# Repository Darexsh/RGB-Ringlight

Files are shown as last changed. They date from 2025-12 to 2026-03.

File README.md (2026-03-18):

* * *

<div align="center">

🌈 RGB Ringlight – LED Chaser
============================

**🟥🟩🟦 RGB LED Chaser using 3 mm LEDs**  

Powered by NE555, CD4017, and a speed control potentiometer

  

   
<sub>Check out my bot in Telegram for an easy project overview.<br>If you want to support more projects, you can leave a small donation for a coffee.</sub>

</div>

* * *

✨ Authors
---------

| Name | GitHub | Role | Contact | Contributions |
| --- | --- | --- | --- | --- |
| **[Darexsh by Daniel Sichler](https://github.com/Darexsh)** | [Link](https://github.com/Darexsh?tab=repositories) | Hardware & Schematic 🖥️🛠️| 📧 [E-Mail](mailto:sichler.daniel@gmail.com) | Concept, Layout, Integration |

* * *

🚀 About the Project
--------------------

This project is an **RGB ring light with a chaser animation**, built entirely from discrete electronics.
The core consists of:
* **NE555:** Clock Generator
* **CD4017:** Decade Counter
* **24 LEDs:** Positioned in Circle shape with with alternatingly positioned red, green and blue LEDs
    
The **chase speed** can be adjusted using a **10 kΩ potentiometer**.
Power is supplied through a **9 V barrel jack (5.5 mm)**.

* * *

🛠️ How It Works
===========

🔁 **Main Function**
* The **NE555** operates in astable mode, generating a variable clock signal.
* The **CD4017** advances one output pin per clock pulse.
* Each LED lights up sequentially → creating the classic **LED chaser effect**.

💡 **LED Layout**

The ring contains **24 LEDs** total:
* 🔴 **D1–D8:** Red
* 🟢 **D9–D16:** Green
* 🔵 **D17–D24:** Blue

🎚️ **Speed Control**
* A **10 kΩ potentiometer (RV1)** adjusts the NE555 frequency.

🔌 **Power Supply**
* **9 V DC input**
* Supplied through a **5.5 mm barrel jack**

* * *

📋 Bill of Materials (BOM)
===========

| Part | Value / Type |
| --- | --- |
| **IC1** | CD4017BE |
| **IC2** | NE555P |
| **LEDs** | 24× 3 mm LEDs (8× red, 8× green, 8× blue) |
| **R1–R24** | 680 Ω |
| **R25** | 10 kΩ |
| **RV1** | 10 kΩ potentiometer |
| **C1** | 10 µF / 25 V |
| **J1** | DC barrel jack 5.5 mm (with switch) |
| **J2** | Socket for CD4017 |
| **J3** | Socket for NE555 |
| **H1** | Mounting hole |

* * *

📜 License
----------

This project is licensed under the **Non-Commercial Software License (MIT-style) v1.0** and was developed as an educational project. You are free to use, modify, and distribute the code for **non-commercial purposes only**, and must credit the author:

**Copyright (c) 2025 Darexsh by Daniel Sichler**

Please include the following notice with any use or distribution:

> Developed by Daniel Sichler aka Darexsh. Licensed under the Non-Commercial Software License (MIT-style) v1.0. See `LICENSE` for details.

The full license is available in the [LICENSE](LICENSE) file.

* * *

<!-- Keep this line! Rendered picture of PCB is going to be displayed after Production files are pushed to branch! -->
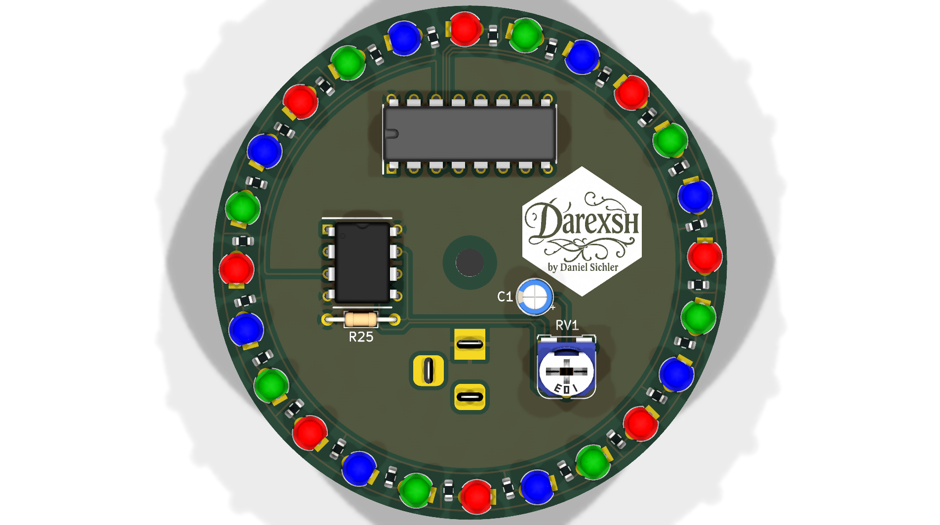
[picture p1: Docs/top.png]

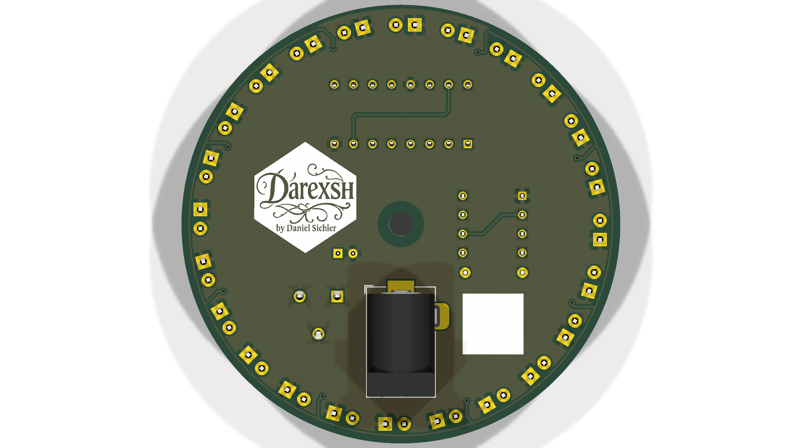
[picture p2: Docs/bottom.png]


<div align="center"> <sub>Created with ❤️ by Daniel Sichler</sub> </div>

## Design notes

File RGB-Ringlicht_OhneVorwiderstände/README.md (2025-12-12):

# KiCAD Project Template
<!-- Keep this line! Rendered picture of PCB will be displayed after production files are pushed to branch -->

This template provides a clean KiCad repository structure for embedded hardware projects, including a GUI-based import script (`kicad_library_manager`) for component management.

---

## Features

Clean structure for hardware development with automated component import and library management.

**DISCLAIMER:** KiCad files are difficult to edit simultaneously. Limit active work on project files to one person at a time; other tasks like research or tests can be done in parallel.

---

## Getting Started

1. **Clone the repository:**

```bash
git clone https://github.com/Ihysol/kicad-template.git
```

2. **Set up your KiCad project:**

* Add symbols, footprints, and 3D models in `Lib-*` folders
* Check for existing footprints online (ComponentSearchEngine, Mouser, Digi-Key)
* Add parts either using the `kicad_library_manager` GUI or manually
* By default, `kicad_library_manager` uses the `library_input` folder located in the `kicad_library_manager` folder to read component files
* Keep all other libraries local; do not use global libraries

3. **Update this README** to describe your project

---

## Ordering Your PCB

* Use Git tags for PCBs sent to production to snapshot the PCB at that moment
* Use the [KiCAD BOM Mouser Order Script](https://github.com/Ihysol/KiCAD_BOM_Mouser_Order_Script) to generate a BOM cart automatically

---

## Folder Structure

* **Hardware/**: KiCad files, symbols, footprints, and 3D models. Add custom footprints here
* **Production/**: Final Gerber files for PCB ordering
* **Docs/**: Documentation, notes, and changelogs. Link datasheets externally and update after production

---

## Version Control

* Use the main branch for the current hardware version
* Tag commits corresponding to production-ready PCBs (e.g., `v1.0`)
* Keep each repository dedicated to a single hardware design
* Use separate repositories for multiple PCB projects

---

## Scripts & Tools

* The `kicad_library_manager` GUI is located in `Hardware/cse_manager/`
* Imports and organizes components automatically
* Can be run as a Python script or standalone executable
* By default, it uses the `library_input` folder inside the `cse_makicad_library_managernager` folder to read component files

---

## Best Practices

* Always include local libraries in the repository; avoid using global KiCad libraries
* Use tags to reference production-ready hardware versions
* Limit simultaneous editing on KiCad files to **one person** at a time

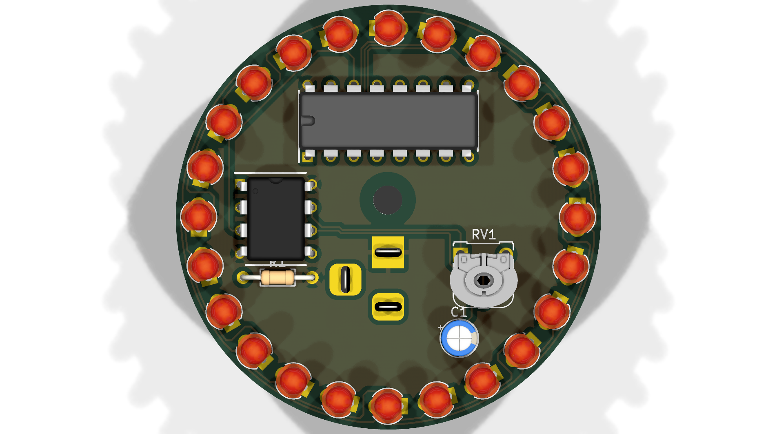
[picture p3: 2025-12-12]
RGB-Ringlicht_OhneVorwiderstände/Hardware/top.png

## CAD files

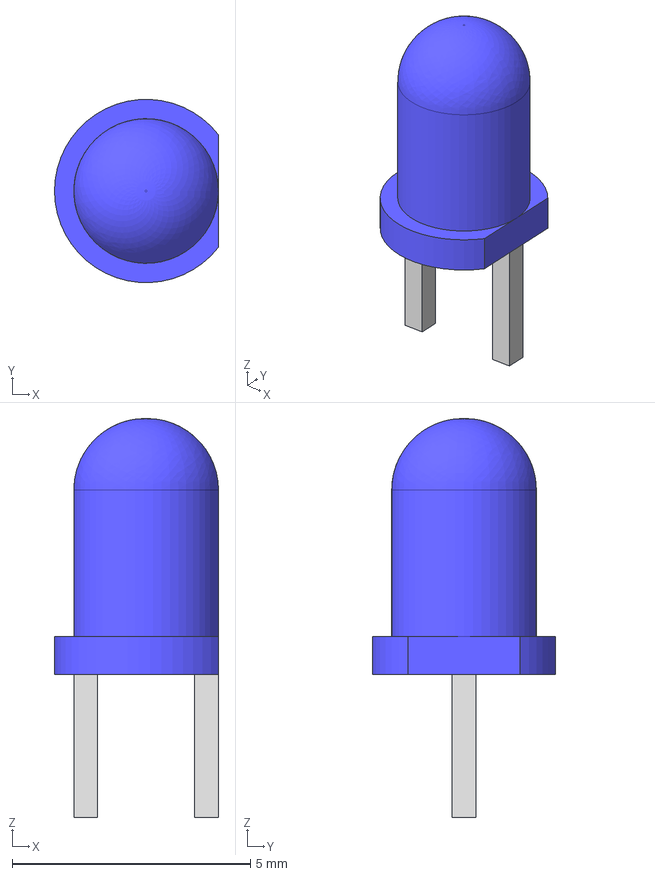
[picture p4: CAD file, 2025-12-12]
Hardware/3dmodels/LED 3mm Blue 3mm Leads.step
3.45 x 3.85 x 8.38 mm
LEDBody
Lead1Body
Lead2Body

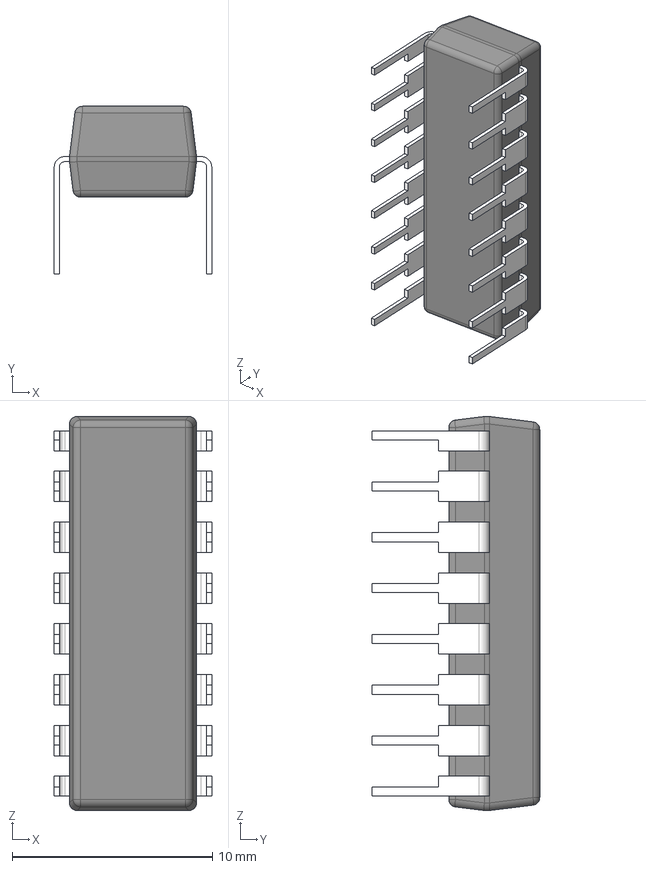
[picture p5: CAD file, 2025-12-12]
RGB-Ringlicht_OhneVorwiderstände/Hardware/3dmodels/CD4017BE.stp
7.87 x 8.37 x 19.7 mm
BODY_N0016A_AF0
LEAD_N0016A_AF1
LEAD_N0016A x 10
LEAD_N0016A_AF3
LEAD_N0016A_AF5
LEAD_N0016A_AF0
LEAD_N0016A_AF2
LEAD_N0016A_AF4

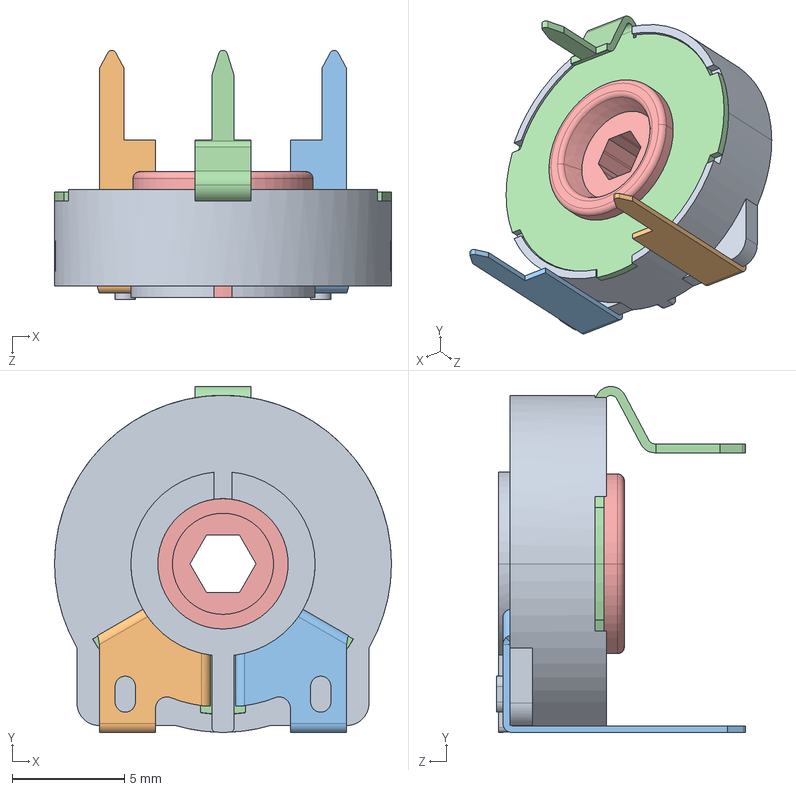
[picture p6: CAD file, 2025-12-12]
RGB-Ringlicht_OhneVorwiderstände/Hardware/3dmodels/Same_Sky_PTN15-F100HB20-H.step
15.0 x 15.4 x 11.1 mm
PTN15 HOUSING
PTN15 VERT TERMINALS
PTN15-F WIPER
PTN15 HEXAGONAL ROTOR

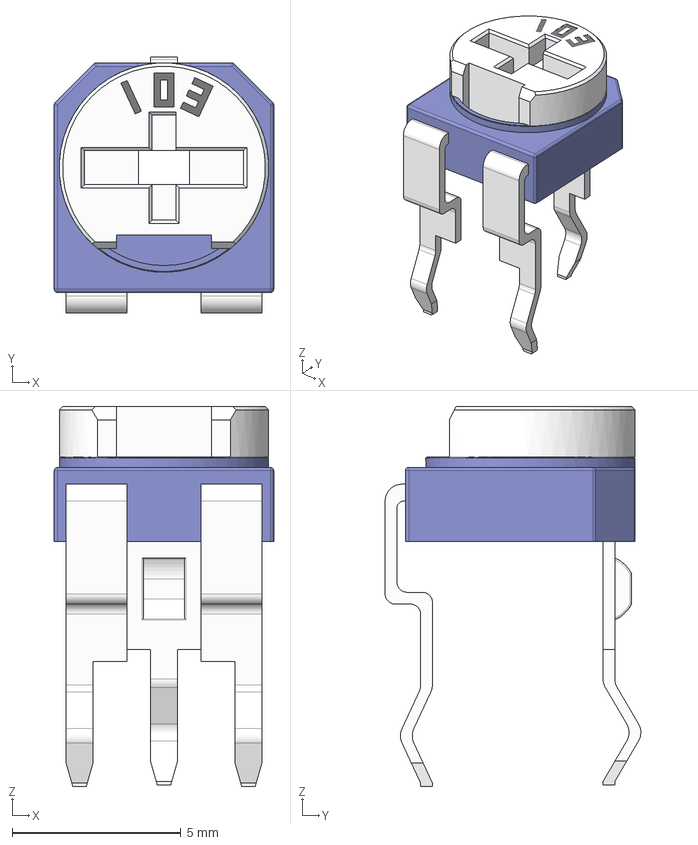
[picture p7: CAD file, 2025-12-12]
Hardware/3dmodels/Trim_Potentiometer_103.step
6.50 x 7.57 x 11.2 mm

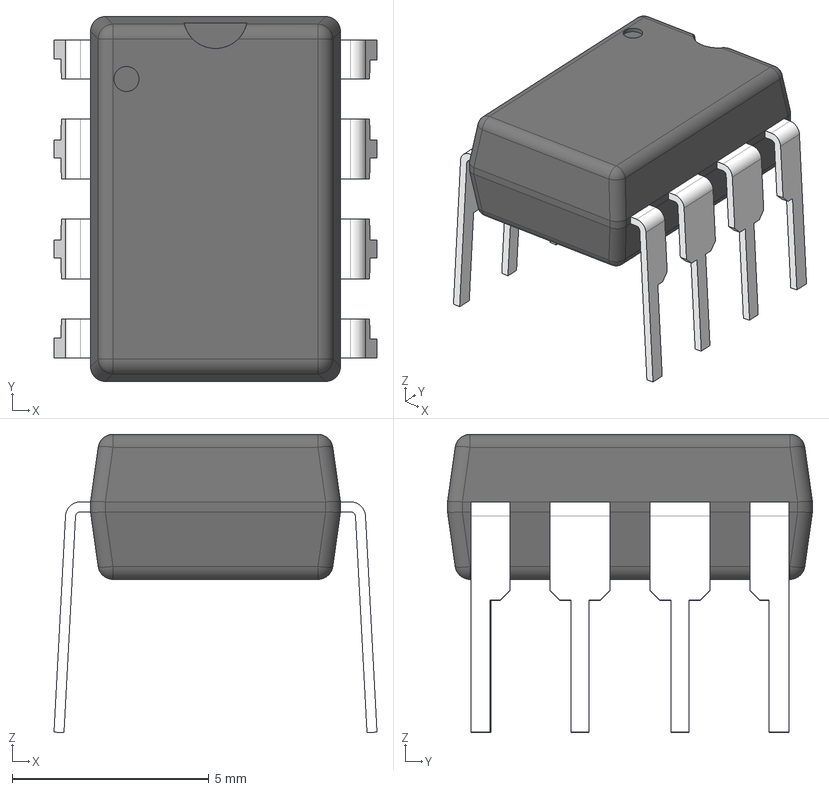
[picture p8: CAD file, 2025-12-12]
RGB-Ringlicht_OhneVorwiderstände/Hardware/3dmodels/NE555P.stp
8.20 x 9.27 x 7.58 mm
BODY_P0008A
LEAD_P0008A x 4
LD_LHALF_P0008A x 2
LD_RHALF_P0008A x 2

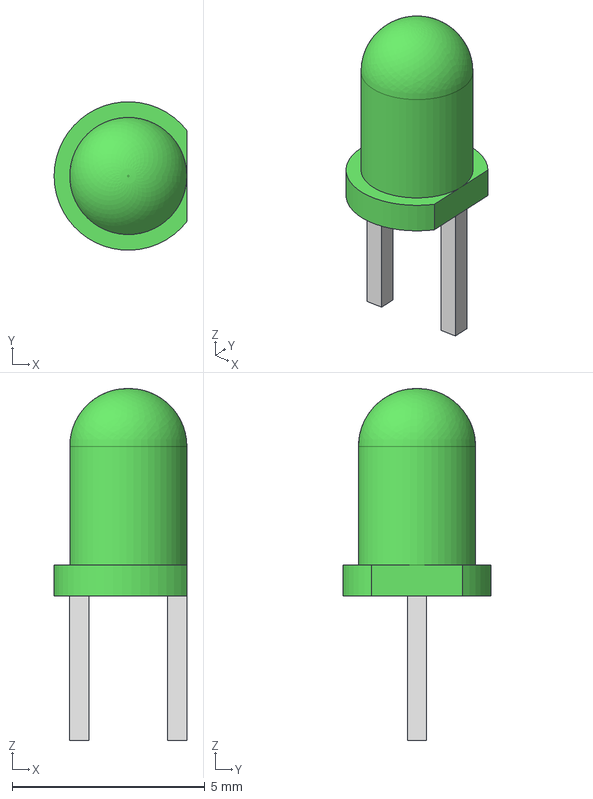
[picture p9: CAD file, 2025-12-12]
Hardware/3dmodels/LED 3mm Green 3mm Leads.step
3.45 x 3.85 x 9.13 mm
LEDBody
Lead1Body
Lead2Body

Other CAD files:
Hardware/3dmodels/LED 3mm Red 3mm Leads.step

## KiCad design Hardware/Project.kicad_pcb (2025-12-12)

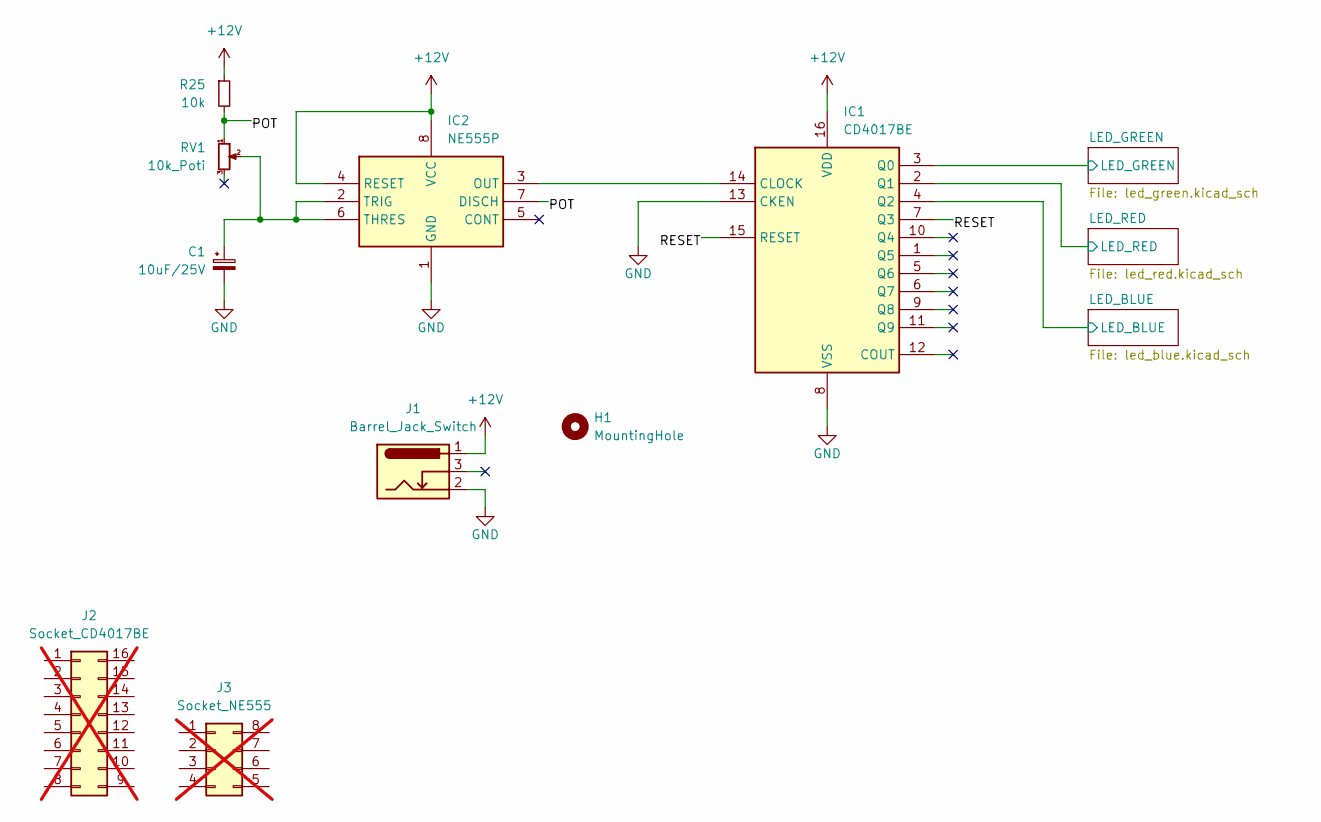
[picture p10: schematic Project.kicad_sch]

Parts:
C1: 10uF/25V; CP_Radial_D4.0mm_P2.00mm; LCSC C43347
H1: MountingHole; MountingHole_3.2mm_M3
IC1: CD4017BE; LCSC C51898328
IC2: NE555P; LCSC C51927330
J1: Barrel_Jack_Switch; BarrelJack_Horizontal; LCSC C3096082
J2: Socket_CD4017BE; LCSC C2326; not fitted
J3: Socket_NE555; LCSC C72124; not fitted
R25: 10k; R_Axial_DIN0204_L3.6mm_D1.6mm_P7.62mm_Horizontal; LCSC C2903232
RV1: 10k_Poti; Potentiometer_Runtron_RM-065_Vertical; LCSC C5205021

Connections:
+12V: IC1.16 (VDD), IC2.4 (RESET), IC2.8 (VCC), J1.1, R25.1
/LED_BLUE/LED_BLUE: IC1.4 (Q2); also elsewhere on the board
/LED_GREEN/LED_GREEN: IC1.3 (Q0); also elsewhere on the board
/LED_RED/LED_RED: IC1.2 (Q1); also elsewhere on the board
/POT: IC2.7 (DISCH), R25.2, RV1.1
/RESET: IC1.7 (Q3), IC1.15 (RESET)
GND: C1.2, IC1.8 (VSS), IC1.13 (CKEN), IC2.1 (GND), J1.2; also elsewhere on the board
unnamed: IC1.14 (CLOCK), IC2.3 (OUT)
unnamed: C1.1, IC2.2 (TRIG), IC2.6 (THRES), RV1.2

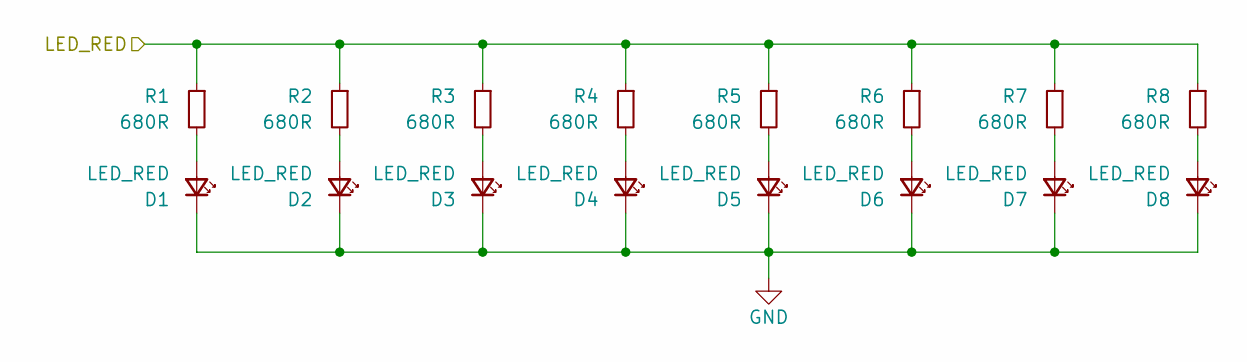
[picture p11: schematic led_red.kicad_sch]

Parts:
D1, D2, D3, D4, D5, D6, D7, D8: LED_RED; LED_D3.0mm; LCSC C2895470
R1, R2, R3, R4, R5, R6, R7, R8: 680R; R_0603_1608Metric

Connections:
/LED_RED/LED_RED: R1.1, R2.1, R3.1, R4.1, R5.1, R6.1, R7.1, R8.1; also elsewhere on the board
GND: D1.1 (K), D2.1 (K), D3.1 (K), D4.1 (K), D5.1 (K), D6.1 (K), D7.1 (K), D8.1 (K); also elsewhere on the board
unnamed: D1.2 (A), R1.2
unnamed: D2.2 (A), R2.2
unnamed: D3.2 (A), R3.2
unnamed: D4.2 (A), R4.2
unnamed: D5.2 (A), R5.2
unnamed: D6.2 (A), R6.2
unnamed: D7.2 (A), R7.2
unnamed: D8.2 (A), R8.2

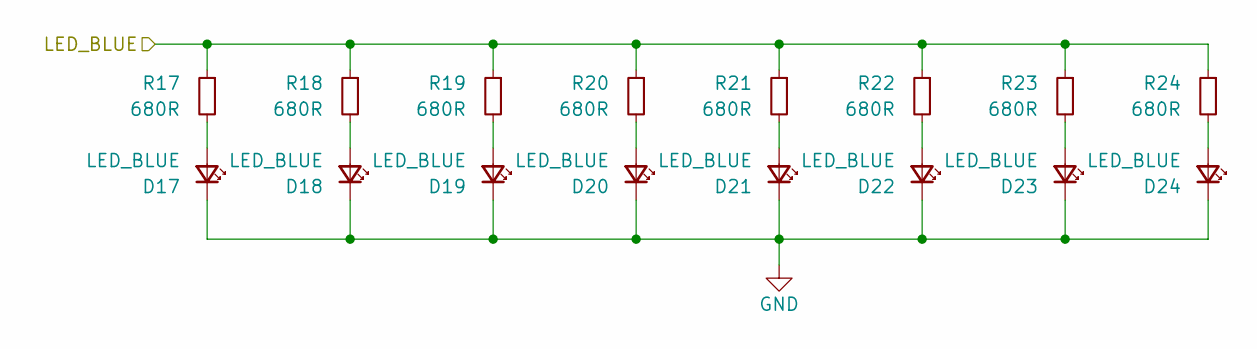
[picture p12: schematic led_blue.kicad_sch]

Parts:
D17, D18, D19, D20, D21, D22, D23, D24: LED_BLUE; LED_D3.0mm; LCSC C2895474
R17, R18, R19, R20, R21, R22, R23, R24: 680R; R_0603_1608Metric

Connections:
/LED_BLUE/LED_BLUE: R17.1, R18.1, R19.1, R20.1, R21.1, R22.1, R23.1, R24.1; also elsewhere on the board
GND: D17.1 (K), D18.1 (K), D19.1 (K), D20.1 (K), D21.1 (K), D22.1 (K), D23.1 (K), D24.1 (K); also elsewhere on the board
unnamed: D17.2 (A), R17.2
unnamed: D18.2 (A), R18.2
unnamed: D19.2 (A), R19.2
unnamed: D20.2 (A), R20.2
unnamed: D21.2 (A), R21.2
unnamed: D22.2 (A), R22.2
unnamed: D23.2 (A), R23.2
unnamed: D24.2 (A), R24.2

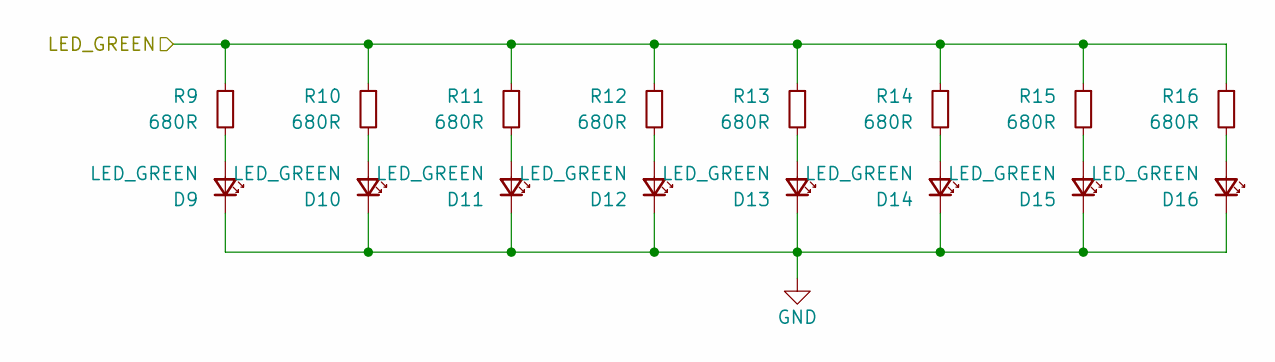
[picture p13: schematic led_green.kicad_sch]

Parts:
D9, D10, D11, D12, D13, D14, D15, D16: LED_GREEN; LED_D3.0mm; LCSC C7470728
R9, R10, R11, R12, R13, R14, R15, R16: 680R; R_0603_1608Metric

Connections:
/LED_GREEN/LED_GREEN: R9.1, R10.1, R11.1, R12.1, R13.1, R14.1, R15.1, R16.1; also elsewhere on the board
GND: D9.1 (K), D10.1 (K), D11.1 (K), D12.1 (K), D13.1 (K), D14.1 (K), D15.1 (K), D16.1 (K); also elsewhere on the board
unnamed: D9.2 (A), R9.2
unnamed: D10.2 (A), R10.2
unnamed: D11.2 (A), R11.2
unnamed: D12.2 (A), R12.2
unnamed: D13.2 (A), R13.2
unnamed: D14.2 (A), R14.2
unnamed: D15.2 (A), R15.2
unnamed: D16.2 (A), R16.2

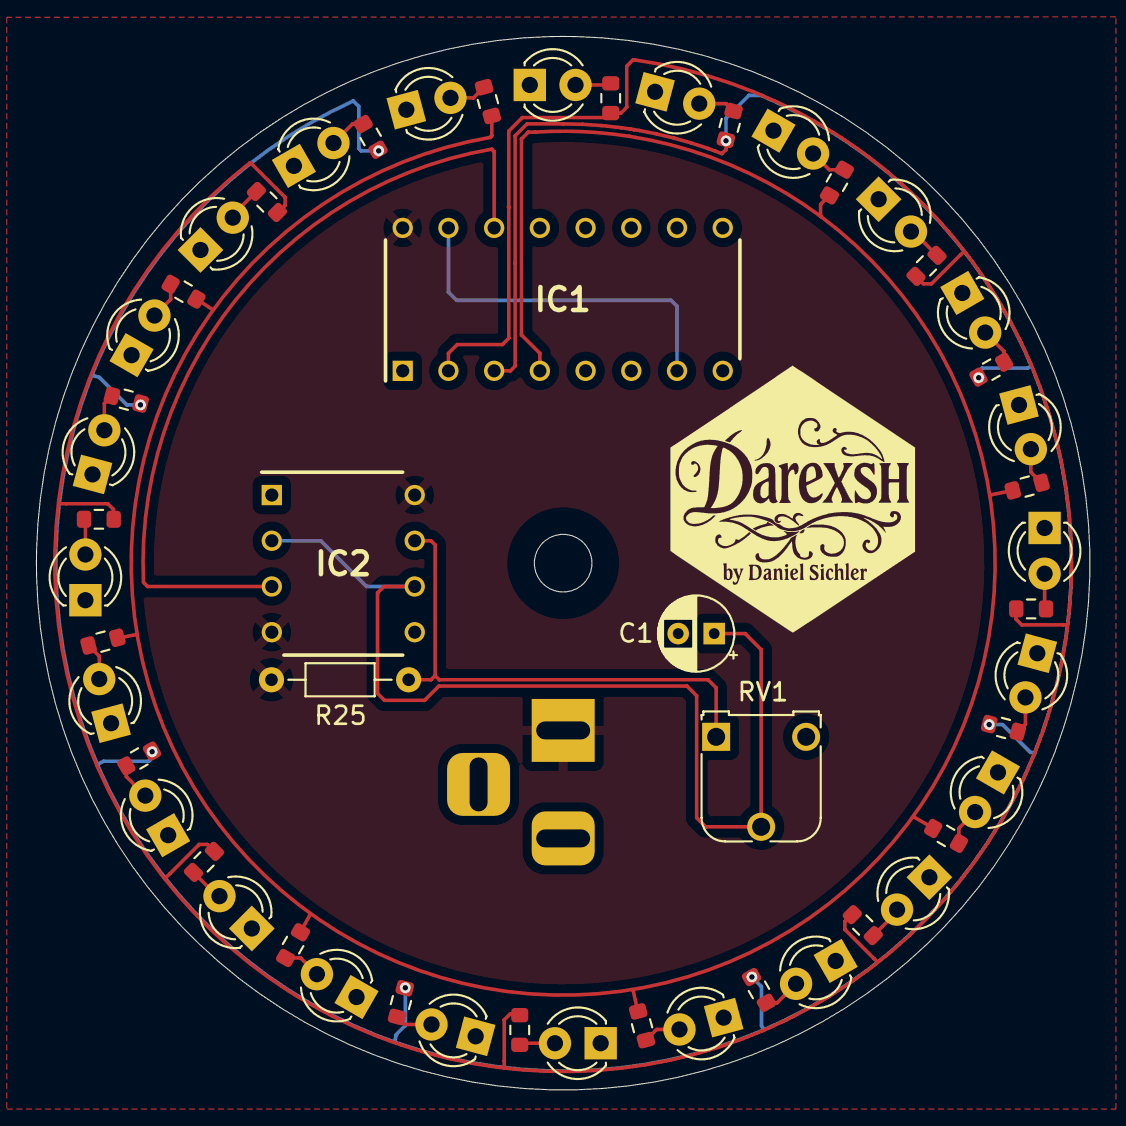
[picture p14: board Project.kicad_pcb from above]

Board: 2 copper layers, 58.5 x 58.5 mm, 55 parts (1 on the bottom side), 33 nets.

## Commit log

2025-12-12 Added Ringlight
    [CD4017BE.stp, NE555P.stp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]
2025-12-12 Added first PCB without series resistor
    [CD4017BE.stp, NE555P.stp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]
2025-12-12 Correct appearances in 3D viewer and rendered pictures
    [LED 3mm Blue 3mm Leads.step, LED 3mm Green 3mm Leads.step, LED 3mm Red 3mm Leads.step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]

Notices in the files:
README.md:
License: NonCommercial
